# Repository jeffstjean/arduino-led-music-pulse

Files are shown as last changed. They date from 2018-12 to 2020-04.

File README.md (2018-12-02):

# Arduino Led Music Pulse

Controls an LED light-strip using an Arduino to pulse to the beat of a input from a 3.5mm audio device
[View the Demo.](https://youtu.be/wHUdtZS7I78)

## Getting Started
---

### Prerequisites

You will need to download the following libraries:
* [ArduinoFFT](https://github.com/kosme/arduinoFFT)
* [Adafruit_NeoPixel](https://github.com/adafruit/Adafruit_NeoPixel)
* [MicroSmooth](https://github.com/asheeshr/Microsmooth)

### Hardware

Read [HARDWARE.md](HARDWARE.md) to make sure you are using the correct parts.

### Schematic

Please reference [audio-in-schematic.png](audio-in-schematic.png) to connect the audio-in circuit correctly.  
For the light strip: 5V connects to Arduino/external 5V, GND to Arduino/external GND and DATA to Arduino's Digital Pin 6.

### Installing

Once you have downloaded the files and libraries, upload the code to your Arduino.  
You can then plug in your phone or computer to the 3.5mm audio jack.  
Provde power to your arduino and begin playing music.  

## Authors

* **Jeff St. Jean** - *Initial work* - [JeffStJean](https://github.com/jeffstjean)

## License

This project is licensed under the GNU v3 License - see the [LICENSE](LICENSE) file for details

## Acknowledgments

[Devon Crawford](https://www.youtube.com/channel/UCDrekHmOnkptxq3gUU0IyfA) for the inspiration for this project!  
[This StackExchange post](https://arduino.stackexchange.com/questions/25483/audio-input-into-a0) for help getting the voltage divider correctly wired.  
[This Arduino Forum post](https://forum.arduino.cc/index.php?topic=508537.0) for guidance.

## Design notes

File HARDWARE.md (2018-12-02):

# Arduino Led Music Pulse: Hardware

This project was created using the following parts. Components can be interchanged, however there is no guarantee they will function as intended.

## Parts List

### Arduino

* [Arduino UNO Rev3](https://store.arduino.cc/usa/arduino-uno-rev3)
* [USB Type A Male to Type B Male](https://www.amazon.ca/AmazonBasics-USB-2-0-Cable-Male/dp/B00BCWALHM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)

### Audio-In

* [3.5mm Jack](https://www.mycablemart.com/store/cart.php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)
* [10 uF Capacitor](https://www.digikey.ca/product-detail/en/kemet/C320C106J3R5TA7301/C320C106J3R5TA7301-ND/6673788)
* [10k ohm Resistor x2](https://www.digikey.ca/product-detail/en/yageo/RSF200JB-73-10K/10KW-2-ND/18342)

### Light-Strip

* [LED RGB Strip - Addressable, Bare (1m)](https://www.sparkfun.com/products/12025)

### Miscellaneous

* [Jumper Wires](https://www.sparkfun.com/products/124)
* [Breadboard](https://www.sparkfun.com/products/12002)

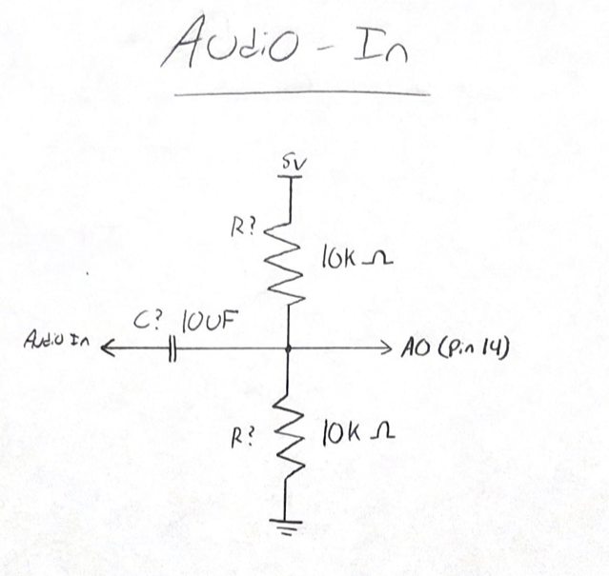
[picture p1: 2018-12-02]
audio-in-schematic.png

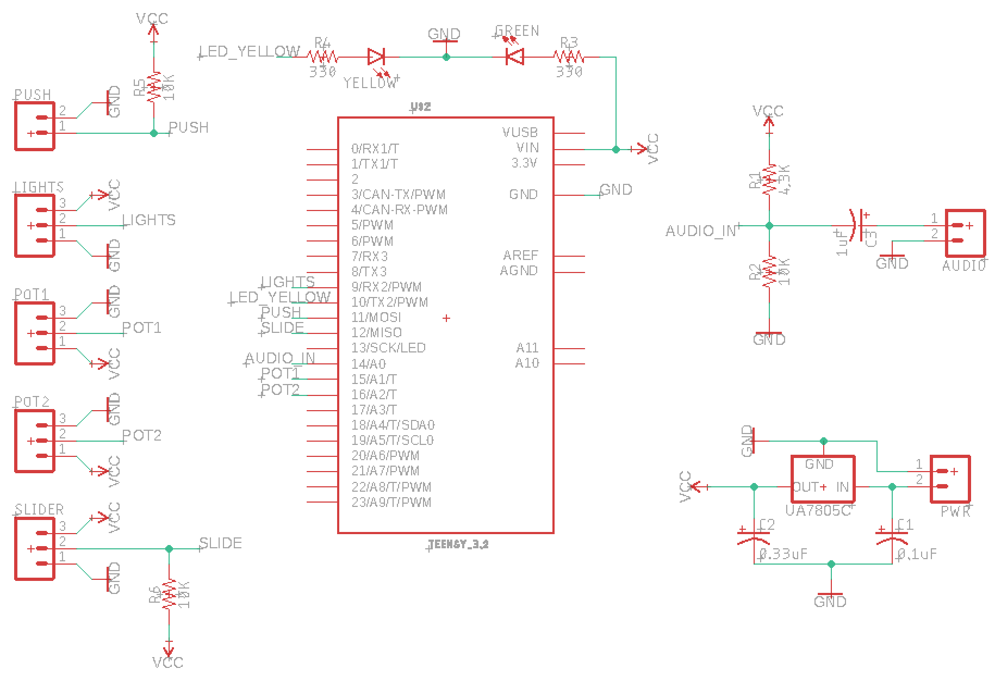
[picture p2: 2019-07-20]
Schematic/schematic_ref.png

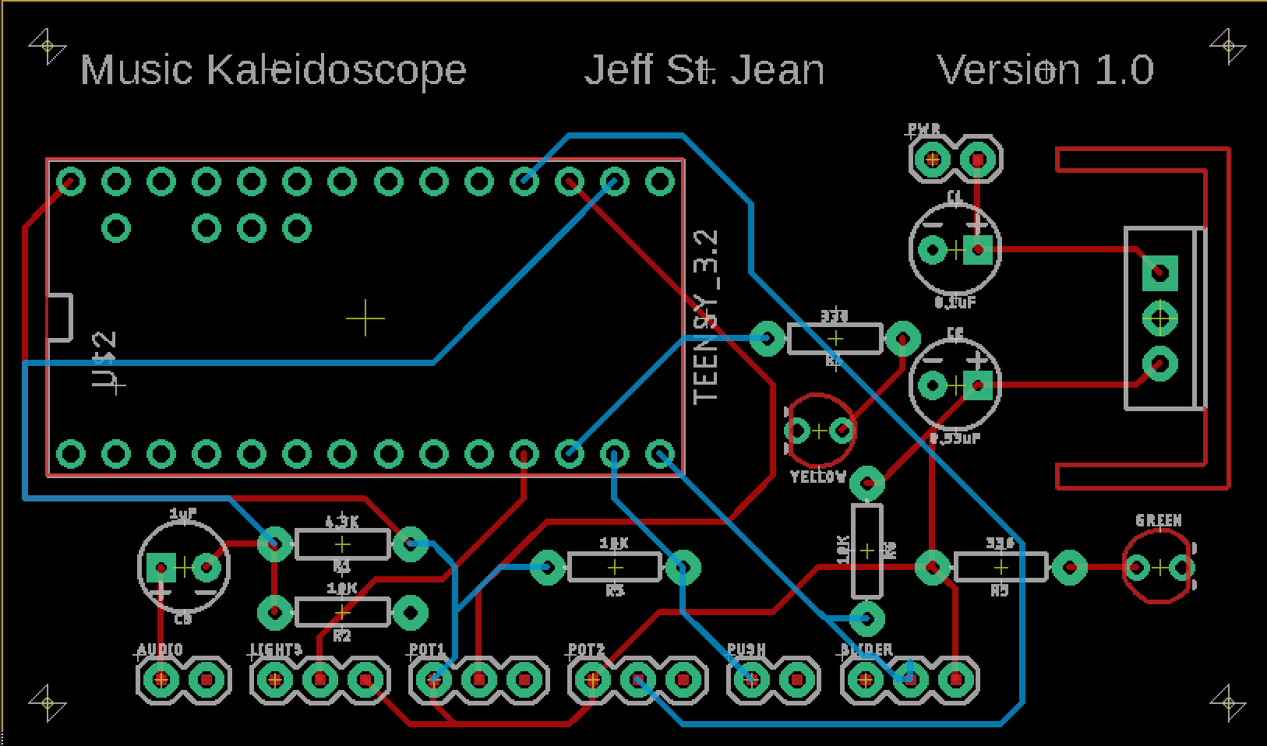
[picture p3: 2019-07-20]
Schematic/board_ref.png

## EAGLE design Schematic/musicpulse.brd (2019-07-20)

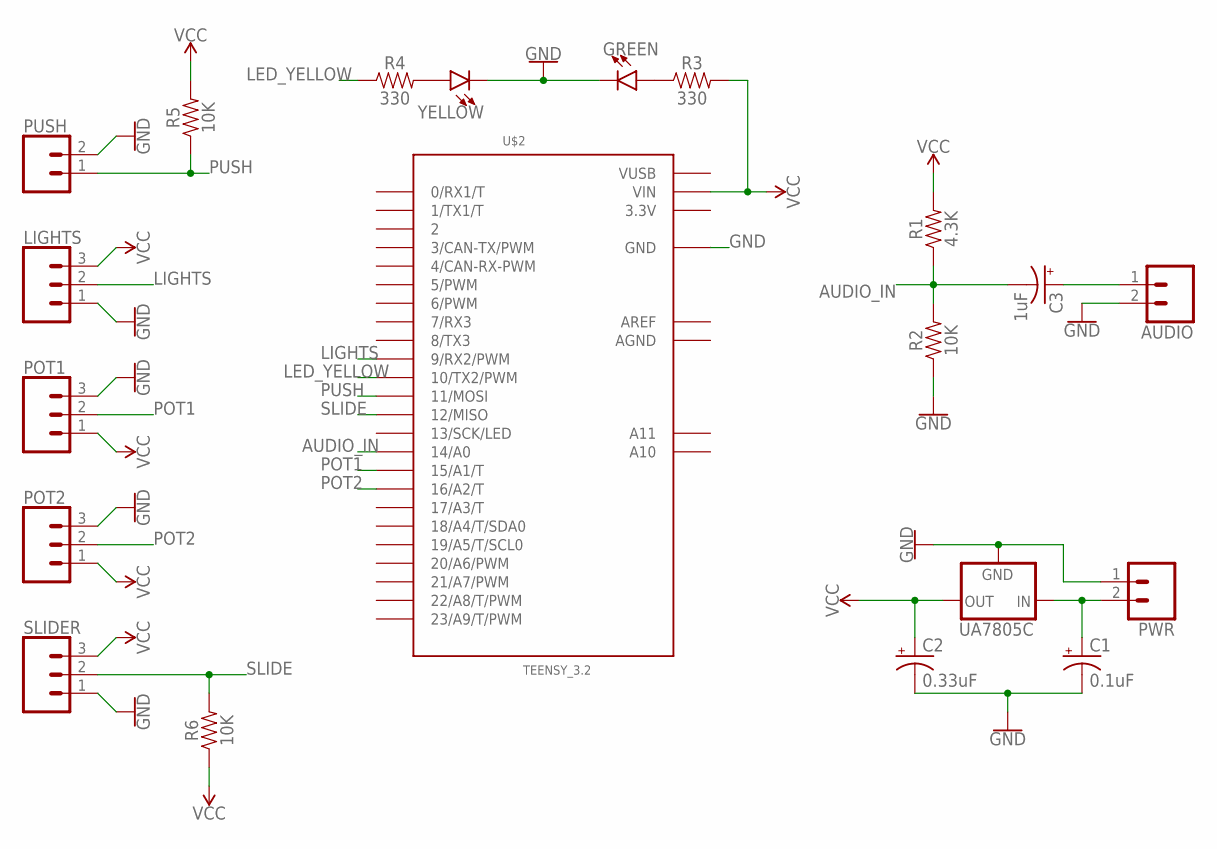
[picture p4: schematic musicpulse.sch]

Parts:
AUDIO: CONN_02; 1X02
C1: 0.1uF; CPOL-RADIAL-2.5MM-5MM
C2: 0.33uF; CPOL-RADIAL-2.5MM-5MM
C3: 1uF; CPOL-RADIAL-2.5MM-5MM
GREEN: LED-3MM-NO_SILK; LED_3MM-NS
LIGHTS: CONN_03; 1X03
POT1, POT2: CONN_03; 1X03
PUSH: CONN_02; 1X02
PWR: CONN_02; 1X02
R1: 4.3K; AXIAL-0.3
R2, R5, R6: 10K; AXIAL-0.3
R3, R4: 330; AXIAL-0.3
SLIDER: CONN_03; 1X03
U$2: TEENSY_3.2; TEENSY_3.0-3.2&LC_DIL+4
UA7805C: V_REG_78XXSINK; TO220-IGO
YELLOW: LED-3MM-NO_SILK; LED_3MM-NS

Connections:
3.3V: U$2.3.3V
AGND: U$2.AGND
AREF: U$2.AREF
AUDIO_IN: C3.2 (-), R1.P$1 (1), R2.P$2 (2), U$2.14/A0
GND: AUDIO.2, C1.2 (-), C2.2 (-), GREEN.K (C), LIGHTS.1, POT1.3, POT2.3, PUSH.2, PWR.1, R2.P$1 (1), SLIDER.1, U$2.GND, UA7805C.GND, YELLOW.K (C)
LED_YELLOW: R4.P$1 (1), U$2.10 (10/TX2/PWM)
LIGHTS: LIGHTS.2, U$2.9 (9/RX2/PWM)
unnamed: C1.1 (+), PWR.2, UA7805C.IN
unnamed: R4.P$2 (2), YELLOW.A
unnamed: GREEN.A, R3.P$1 (1)
unnamed: AUDIO.1, C3.1 (+)
POT1: POT1.2, U$2.15/A1 (15/A1/T)
POT2: POT2.2, U$2.16/A2 (16/A2/T)
PUSH: PUSH.1, R5.P$1 (1), U$2.11 (11/MOSI)
SLIDE: R6.P$2 (2), SLIDER.2, U$2.12 (12/MISO)
VCC: C2.1 (+), LIGHTS.3, POT1.1, POT2.1, R1.P$2 (2), R3.P$2 (2), R5.P$2 (2), R6.P$1 (1), SLIDER.3, U$2.VIN, UA7805C.OUT
VUSB: U$2.VUSB

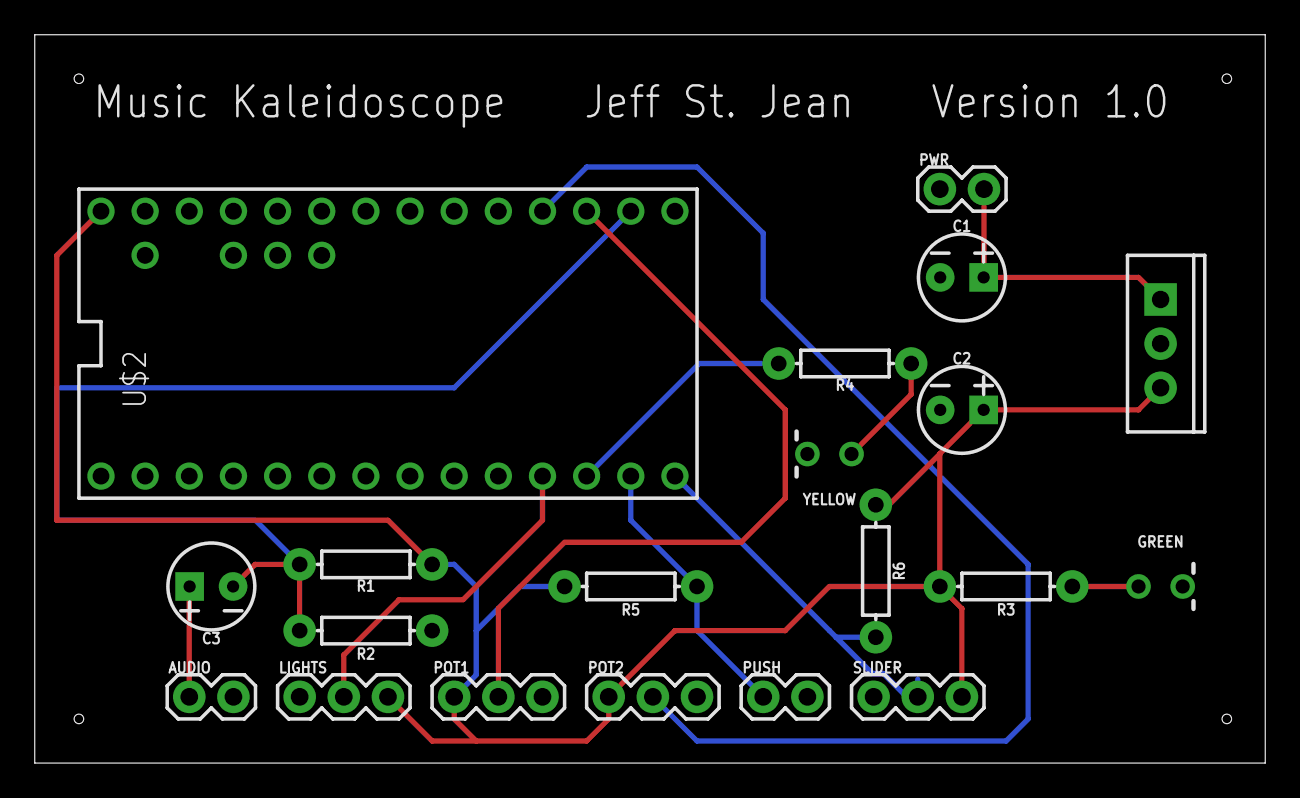
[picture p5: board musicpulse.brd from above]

Board: 2 copper layers, 70.8 x 41.9 mm, 20 parts (0 on the bottom side), 13 nets.

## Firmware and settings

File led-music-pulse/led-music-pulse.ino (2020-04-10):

/*
  led-music-pulse
  Copyright (C) 2020, Jeff St. Jean

  This program is free software; you can redistribute it and/or modify it under the terms of the GNU General Public License as published by the Free Software Foundation; either version 3 of the License, or (at your option) any later version.

*/

#include "arduinoFFT.h" // library for real-time frequency analysis
#include <Adafruit_NeoPixel.h> // library for communicating with light-strip
#include <microsmooth.h> // library for smoothing the input signal

//FFT Variables
#define SAMPLES 32             // must be a power of 2
#define SAMPLING_FREQUENCY 2000 // Hz, must be less than 10000 due to ADC
unsigned int sampling_period_us;
unsigned long microseconds;
arduinoFFT FFT = arduinoFFT();
int musicPin = A0; // audio in pin
uint16_t *ptr; // memory of recent bass values to pass to microsmooth.h
double vReal[SAMPLES]; //   real    array of FFT
double vImag[SAMPLES]; // imaginary array of FFT

// for smoothing of LED brightness
#define ledValueHistoryLength 3
int ledValueHistory[ledValueHistoryLength];

//Light Strip Variables
#define LED_PIN 9 // led pin
int NUM_LEDS = 60; // number of LEDs on light strip
Adafruit_NeoPixel strip = Adafruit_NeoPixel(NUM_LEDS, LED_PIN, NEO_GRB + NEO_KHZ800);

//Program Control Variables
int ledValue; // value to set the led to (0-255)
bool highBassFlag = false; //
int mode = 0; // which colour the leds should be set to
int maximum = 0;

bool reactive_lights_active = false;
const int LIGHT_REACTIVE_ON_DELAY = 100;
const int LIGHT_REACTIVE_OFF_DELAY = 3000;
bool checking_for_change_in_state = false;
long last_change_in_state = 0;
int red = 0, green = 0, blue = 0, brightness = 0;
int wheel_pos = 0;
long last_wheel_update = 0;
const int PASSIVE_SAMPLE_RATE = 500;

void setup() {
  Serial.begin(115200); // for debugging

  strip.begin(); // prepares the light-strip
  strip.show(); // initialize all pixels to 'off'

  sampling_period_us = round(1000000 * (1.0 / SAMPLING_FREQUENCY)); // configure sampling period

  ptr = ms_init(RDP); // sets microsmooth to smoothing mode RDP
  if (ptr == NULL) {
    Serial.println("Not enough memory"); // not enough memory for the array - should never happen
    while (true) ;
  }

  randomSeed(analogRead(A5)); // fetches a random number seed
  mode = random(0, 6); // randomly generates a number to set the mode to
  for (int i = 0; i < ledValueHistoryLength; i++) ledValueHistory[i] = 0;
  delay(100);
}

void loop() {
  // sampling the audio
  for (int i = 0; i < SAMPLES; i++) {
    microseconds = micros();    // overflows after around 70 minutes!

    vReal[i] = analogRead(musicPin);
    vImag[i] = 0;

    while (micros() < (microseconds + sampling_period_us)) { }
  }

  // FFT doing its thing
  FFT.Windowing(vReal, SAMPLES, FFT_WIN_TYP_HAMMING, FFT_FORWARD);
  FFT.Compute(vReal, vImag, SAMPLES, FFT_FORWARD);
  FFT.ComplexToMagnitude(vReal, vImag, SAMPLES);

  double bass = 0; // holds the bass level

  for (int i = 2; i < 15; i++) {
    if (vReal[i] > bass) bass = vReal[i]; // finds the highest frequency within the 'bass' frequency window (2-15)
  }

  if (bass < 100) bass = 0;

  double filteredBass = rdp_filter(bass, ptr); // smooths the input


  if (filteredBass < 185) filteredBass = 170; // sets a floor to avoid random flickering when music is not playing
  if (filteredBass > maximum) maximum = filteredBass;

  int constrainedBass = constrain(filteredBass, 170, 700); // constrain the bass to these values

  if (reactive_lights_active == true) {

    ledValue = map(constrainedBass, 170, 700, 10, 255); // map the bass to analog numbers (10-255) - anything less than 10 looks ba5

    if (ledValue > 130) { // if this value is above the 'bass hit' value...
      if (!highBassFlag) { // if not still apart of a previous bass hit...
        highBassFlag = true; // say that it is a new bass hit
        mode++; // switch to the next mode (colour)
        if (mode == 7) mode = 0; // if overflow, wrap back around
      }
    }
    else {
      if (highBassFlag) highBassFlag = false; // if not a 'bass hit,' set the flag to false
    }

    int avgLedValue = 0;

    for (int i = ledValueHistoryLength - 1; i > 0; i--) {
      ledValueHistory[i] = ledValueHistory[i - 1];
      avgLedValue += ledValueHistory[i];
    }
    avgLedValue += ledValue;
    ledValueHistory[0] = ledValue;
    avgLedValue = round(avgLedValue / (float)ledValueHistoryLength);

    color_switch();

    brightness = avgLedValue;
  }
  else {
    if(millis() - last_wheel_update >= PASSIVE_SAMPLE_RATE) {
      wheel(wheel_pos);
      wheel_pos++;
      if(wheel_pos == 255) wheel_pos = 0;
      last_wheel_update = millis();
      brightness = 20;
    }
  }

  strip.setBrightness(brightness);
  colorSet(red, green, blue);
  strip.show(); // show the strip
  delay(1);
  if (reactive_lights_active == true) {
    if (filteredBass < 185 && !checking_for_change_in_state) {
      // Serial.println("Checking if music stopped");
      checking_for_change_in_state = true;
      last_change_in_state = millis();
    }
    if (checking_for_change_in_state) {
      if (filteredBass >= 185) {
        // Serial.println("No music is still playing");
        checking_for_change_in_state = false;
      }
      if (millis() - last_change_in_state >= LIGHT_REACTIVE_OFF_DELAY) {
        // Serial.println("Music has been off for long enough, switching to passive");
        reactive_lights_active = false;
        checking_for_change_in_state = false;
      }
    }
  }
  else {
    if (filteredBass >= 185 && !checking_for_change_in_state) {
      // Serial.println("Checking if music started");
      checking_for_change_in_state = true;
      last_change_in_state = millis();
    }
    if (checking_for_change_in_state) {
      if (filteredBass < 185) {
        // Serial.println("No music is still stopped");
        checking_for_change_in_state = false;
      }
      if (millis() - last_change_in_state >= LIGHT_REACTIVE_ON_DELAY) {
        // Serial.println("Music has been on for long enough, switching to active");
        reactive_lights_active = true;
        checking_for_change_in_state = false;
      }
    }
  }
}


// sets the colour of the strip - must use strip.show() to actually see the update in real life
void colorSet(int red, int blue, int green) {
  for (uint16_t i = 0; i < strip.numPixels(); i++) {
    strip.setPixelColor(i, red, green, blue);
  }
}

void color_switch() {
  switch (mode) {
    case 0: // purple
      red   = 60;
      blue  = 0;
      green = 255;
      break;
    case 1: // cyan
      red   = 30;
      blue  = 200;
      green = 255;
      break;
    case 2: // yellow
      red   = 100;
      blue  = 100;
      green = 0;
      break;
    case 3: // light blue
      red   = 20;
      blue  = 50;
      green = 255;
      break;
    case 4: // lime green
      red   = 0;
      blue  = 255;
      green = 30;
      break;
    case 5: // red
      red   = 200;
      blue  = 255;
      green = 30;
      break;
    case 6: // orange
      red   = 100;
      blue  = 200;
      green = 30;
      break;
  }
}


// Input values 0 to 255 to get color values that transition R->G->B. 0 and 255
// are the same color. This is based on Adafruit's Wheel() function, which used
// a linear map that resulted in brightness peaks at 0, 85 and 170. This version
// uses a quadratic map to make values approach 255 faster while leaving full
// red or green or blue untouched. For example, Wheel(42) is halfway between
// red and green. The linear function yielded (126, 129, 0), but this one yields
// (219, 221, 0). This function is based on the equation the circle centered at
// (255,0) with radius 255:  (x-255)^2 + (y-0)^2 = r^2
void wheel(byte position) {
  if (position < 85) {
    red = sqrt32((1530 - 9 * position) * position);
    green = sqrt32(65025 - 9 * position * position);
  }
  else if (position < 170) {
    position -= 85;
    red = sqrt32(65025 - 9 * position * position);
    blue = sqrt32((1530 - 9 * position) * position);
  }
  else {
    position -= 170;
    green = sqrt32((1530 - 9 * position) * position);
    blue = sqrt32(65025 - 9 * position * position);
  }
}



// Adapted from https://www.stm32duino.com/viewtopic.php?t=56#p8160
unsigned int sqrt32(unsigned long n) {
  unsigned int c = 0x8000;
  unsigned int g = 0x8000;
  while (true) {
    if (g * g > n) {
      g ^= c;
    }
    c >>= 1;
    if (c == 0) {
      return g;
    }
    g |= c;
  }
}

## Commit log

2019-05-02 Eagle Schematic
    [musicpulse.brd, musicpulse.sch]
2019-05-02 Manufacturing Files
    [copper_bottom.gbr, copper_top.gbr, drills.xln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]
2019-05-02 Updated Gerbers
    [gerber_job.gbrjob, profile.gbr]
2019-05-25 Added schematic
    [musicpulse.brd, musicpulse.sch]
2019-07-16 Changed to through hole. Adjusted some resistor files. Rerouted board. Reprocessed gerbers. Added board and schematic reference pictures.
    [musicpulse.brd, musicpulse.sch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]
2019-07-18 Rerouted board. Added pullup to slider. Changed some resistor values.
    [musicpulse.brd, musicpulse.sch]
2019-07-18 Added missing trace. Reprocessed CAM files.
    [musicpulse.brd, musicpulse.sch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]
2019-07-20 Adjusted slider trace
    [musicpulse.brd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]
2019-07-20 Updated board image

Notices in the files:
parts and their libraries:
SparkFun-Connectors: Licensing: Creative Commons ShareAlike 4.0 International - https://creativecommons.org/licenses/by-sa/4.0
